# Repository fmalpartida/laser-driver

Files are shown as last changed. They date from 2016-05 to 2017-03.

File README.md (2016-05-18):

# Laser Driver
Small compact, constant current source for driving LEDs and lasers up to 4A with PWM capabilities and integrated support to drive 3 loads such as fans.

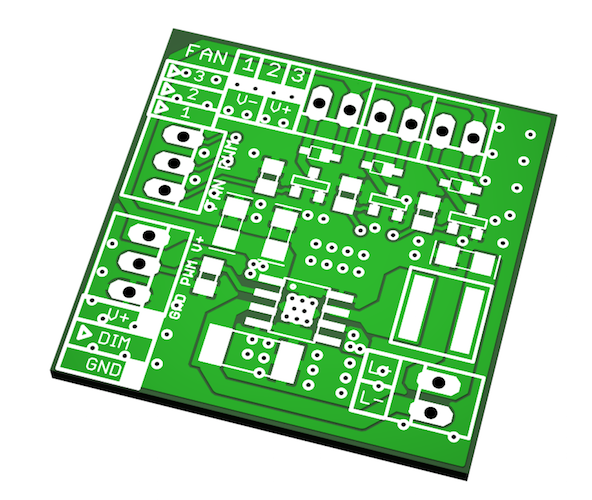
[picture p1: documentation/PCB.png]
Constant current driver PCB Constant current driver


## Board specification
### Schematic
[Last version of the schematic](./documentation/laserDriver_schematic.pdf)

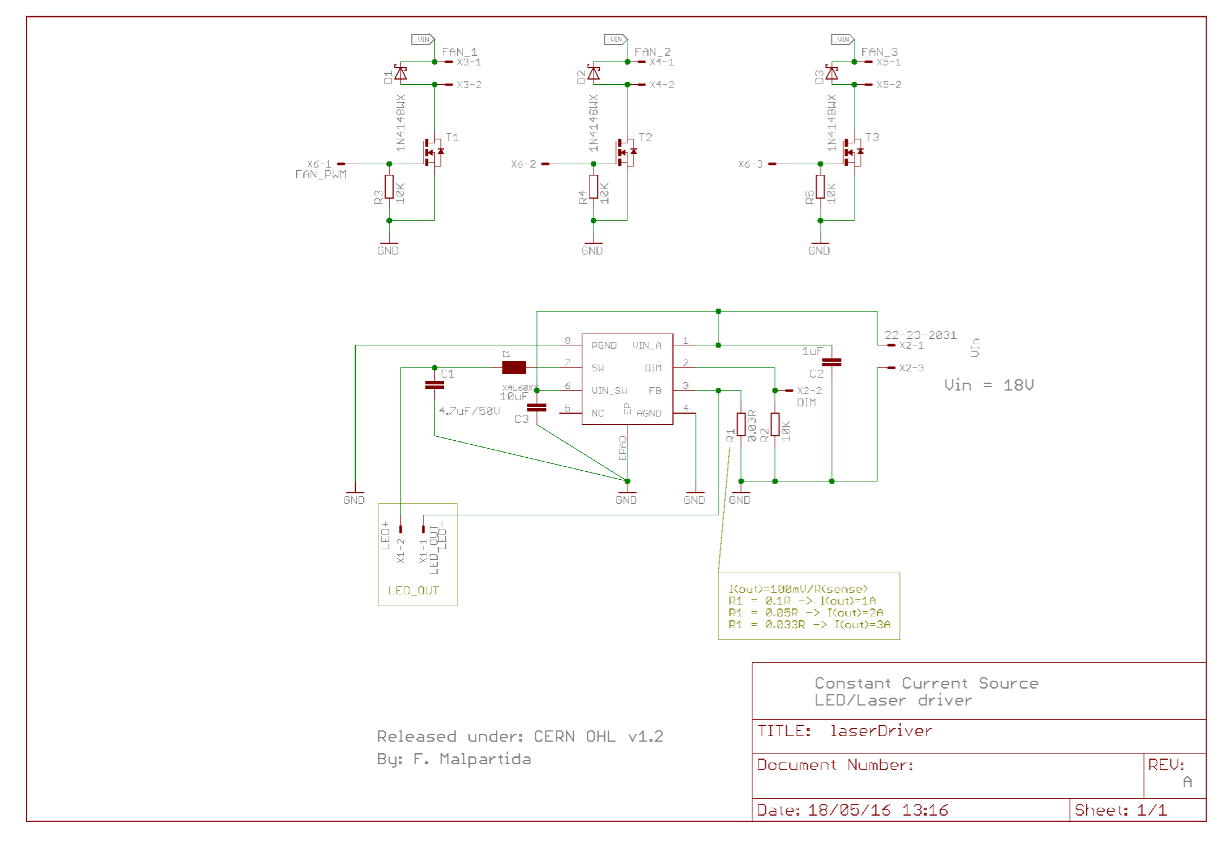
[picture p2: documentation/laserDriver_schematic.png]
Schematic Constant current driver schematic


### Electrical characteristics
   **V(in) range:**  4V..18V, *observe input caps ratings*

   **Max. main load current:** 3.3A *observe inductor ratings*

   **Max. aux load currents:** 500mA *depends on transistor selection*

   **Dim. threshold voltage:** 1.2V

   **Duty cycle range:** 0%..100%

   **Soft start duration:** 1.2ms

   **Dim. frequency range:** 400Hz..4KHz

### Mechanical
   **Board dimensions:** 32mm x 32mm

   **Supply and main load dimming:** 1 x 3 pin, 2.54mm connector

   **Main load connector:** 1 x 2 pin, 2.54mm connector

   **Aux. load dimm. connector:** 1 x 3 pin, 2.54mm connector

   **Aux. load connector:** 3 x 2 pin, 2.54mm connector

   **PCB fabrication:** Pattern class 6, drills clase C. Any cheap PCB manufacturer should be more than capable of making your boards. *Do not shrink track widths.*

*Observe connector current ratings for your application.*

### Measured performance
   **Performance:** Measure performance 83% @ 12V, 1A load. Tested with a 3W LED.

## Operation and setup

Constant current driver PCB Constant current driver

Connect power supply to the supply and main load dimming connector observing the polarity
(V+, DIM, V-) within the board's tolerance and ensure that your supply is capable of sourcing
the current required by your load.

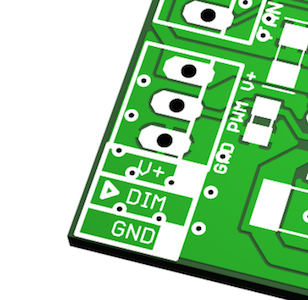
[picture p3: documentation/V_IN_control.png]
Supply Supply and main load dimming


Connect the load (LED or laser driver) observing the polarity of your device.

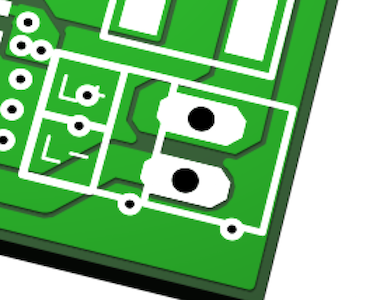
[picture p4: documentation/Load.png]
Load out


If you use auxiliary loads connect them to the auxiliary load connectors and observe their polarity.
The board has built in freewheel diodes, you should be good to go with any type of load provided you don't
exceed switching ratings.

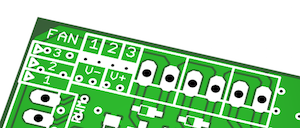
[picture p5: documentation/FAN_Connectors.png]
Fan connector Auxiliary load out


Each auxiliary load channel is controlled with a control signal from the aux load connector. By default
loads are inactive. A voltage level of 5V (depending on your FET selection) will activate each channel.

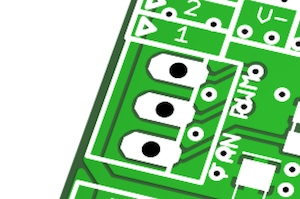
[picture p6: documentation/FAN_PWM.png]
Fan control Auxiliary load control


### Soft start
The board is configured to do a soft start. Apply a 1.2ms (minimum) pulse to the dimm pin before
starting the PWM operation.

## Waveforms and captures
A couple of waveform capture showing the performance of the driver. Measurement setup:
* Supply voltage: 5V
* Load current: 1A

To start the driver it needs a 1.1ms pulse on the dimming pin.
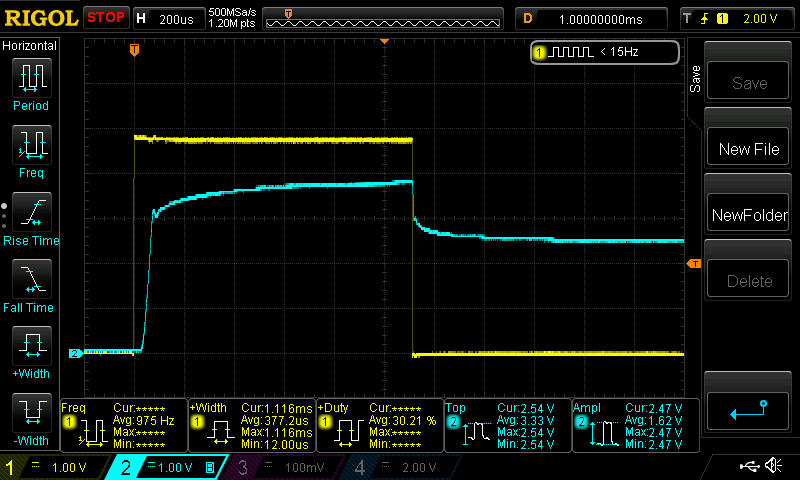
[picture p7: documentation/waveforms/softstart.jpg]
Soft Start Soft start pulse


976Hz PWM duty cycle captures.
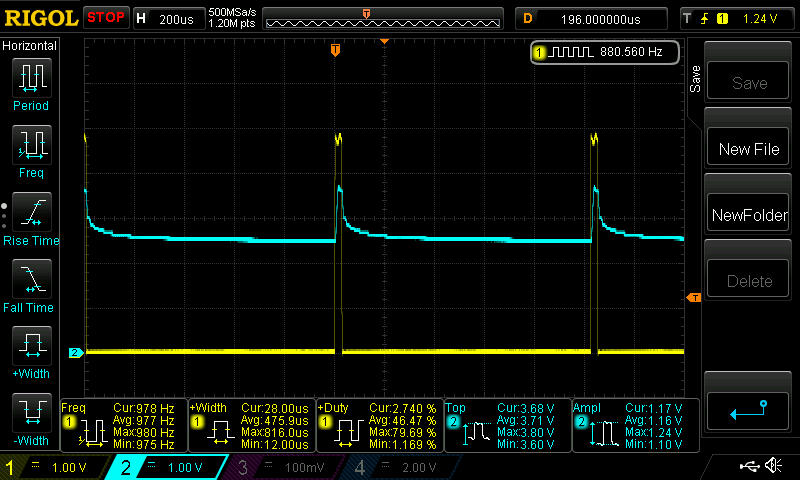
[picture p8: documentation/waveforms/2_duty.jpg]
2% duty cycle 2% duty cycle dimm

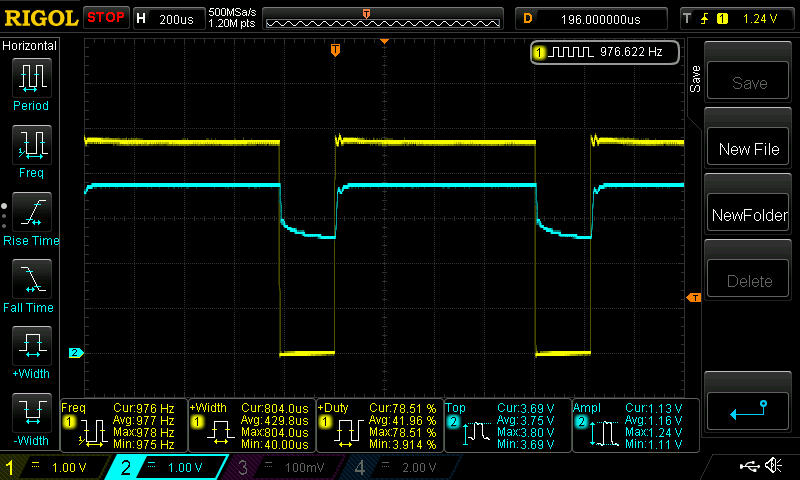
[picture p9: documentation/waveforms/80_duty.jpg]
80% duty cycle 80% duty cycle dimm


Raising edge, measuring directly the LED voltage on switch on. 10us, raising edge with very little
overshoot and ringing. Very decent current control and regulation.
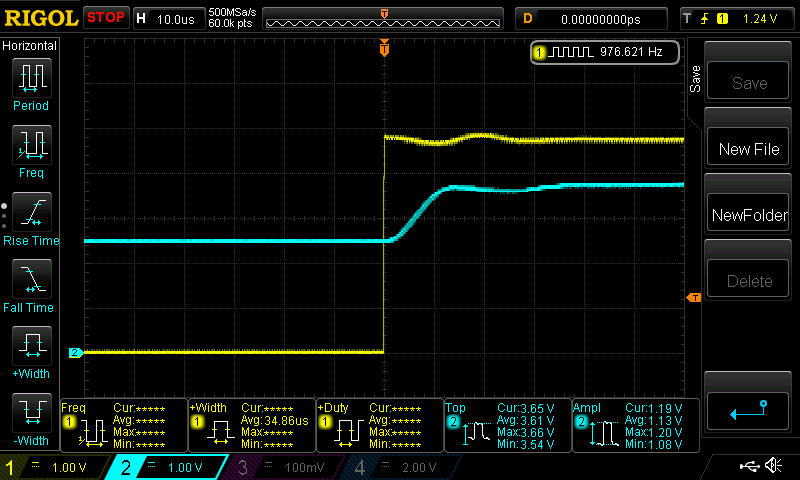
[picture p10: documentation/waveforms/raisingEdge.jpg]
Raising Edge Raising edge 10us


Ripple and noise is around 20mV, I think that about half of it comes from my measurement setup. 20MHz
bandwidth limit.
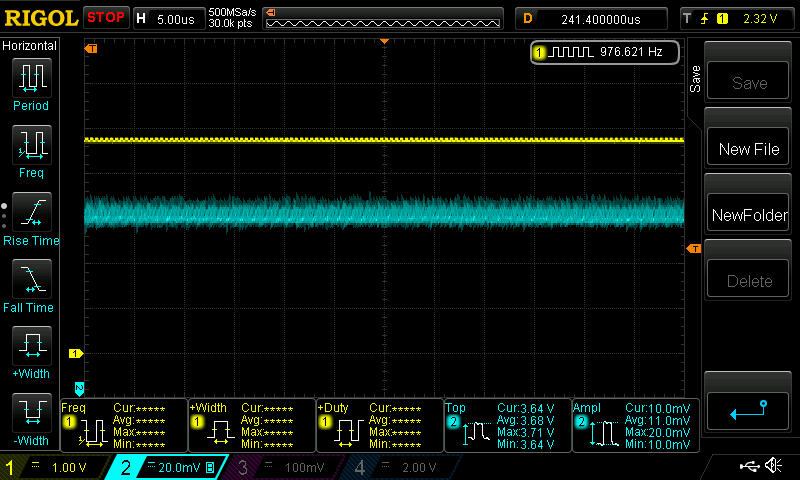
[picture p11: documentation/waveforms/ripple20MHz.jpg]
Ripple Ripple at 1A


## Disclaimer
The board has only been tested to switch a 3W LED driven at 1A. It should be more than capable of reaching
it's full specifications provided that you don't exceed the current ratings of the components you mount.

## License
The board is released under the CERN OHL v1.2 but if you like it and use it you can buy me some beer.
If you use it and/or do any derivative work from it, be nice and give attribution to the source.

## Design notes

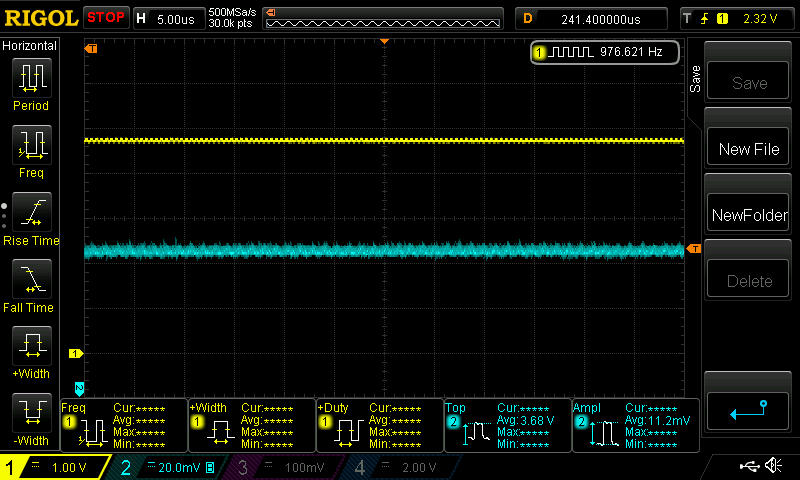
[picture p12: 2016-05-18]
documentation/waveforms/rippleFiltered.jpg

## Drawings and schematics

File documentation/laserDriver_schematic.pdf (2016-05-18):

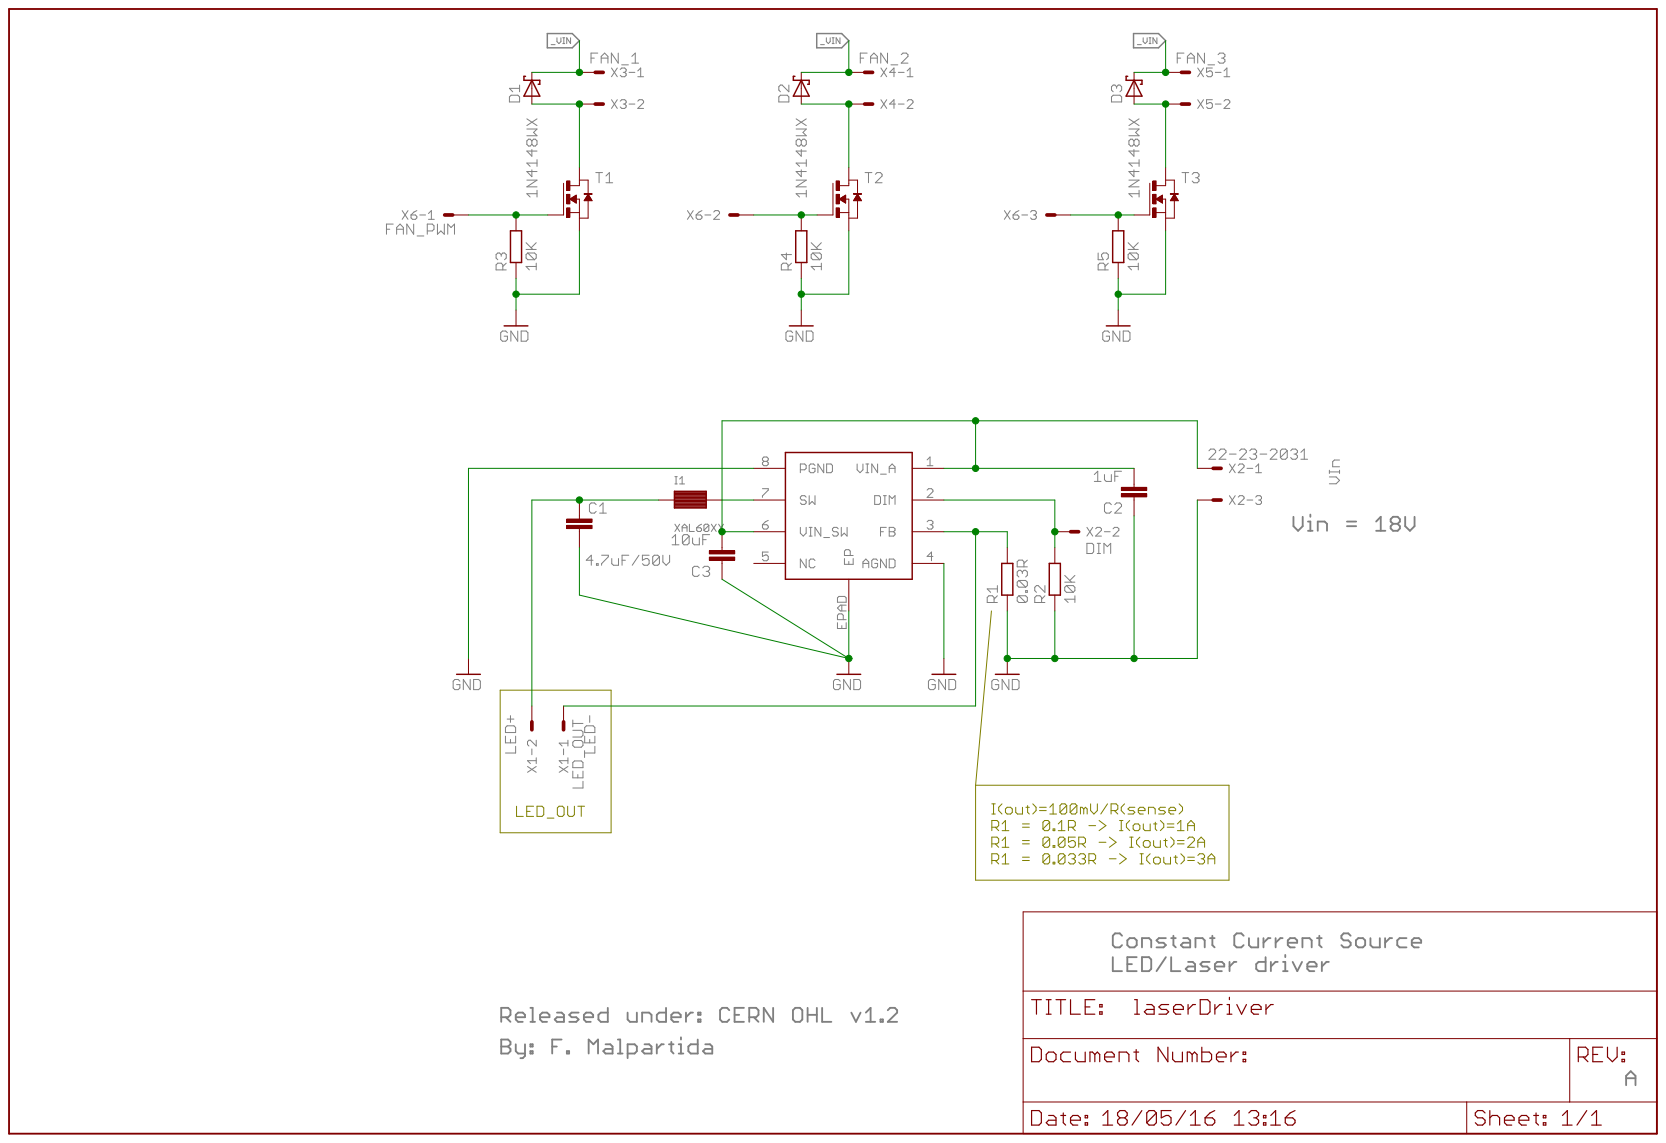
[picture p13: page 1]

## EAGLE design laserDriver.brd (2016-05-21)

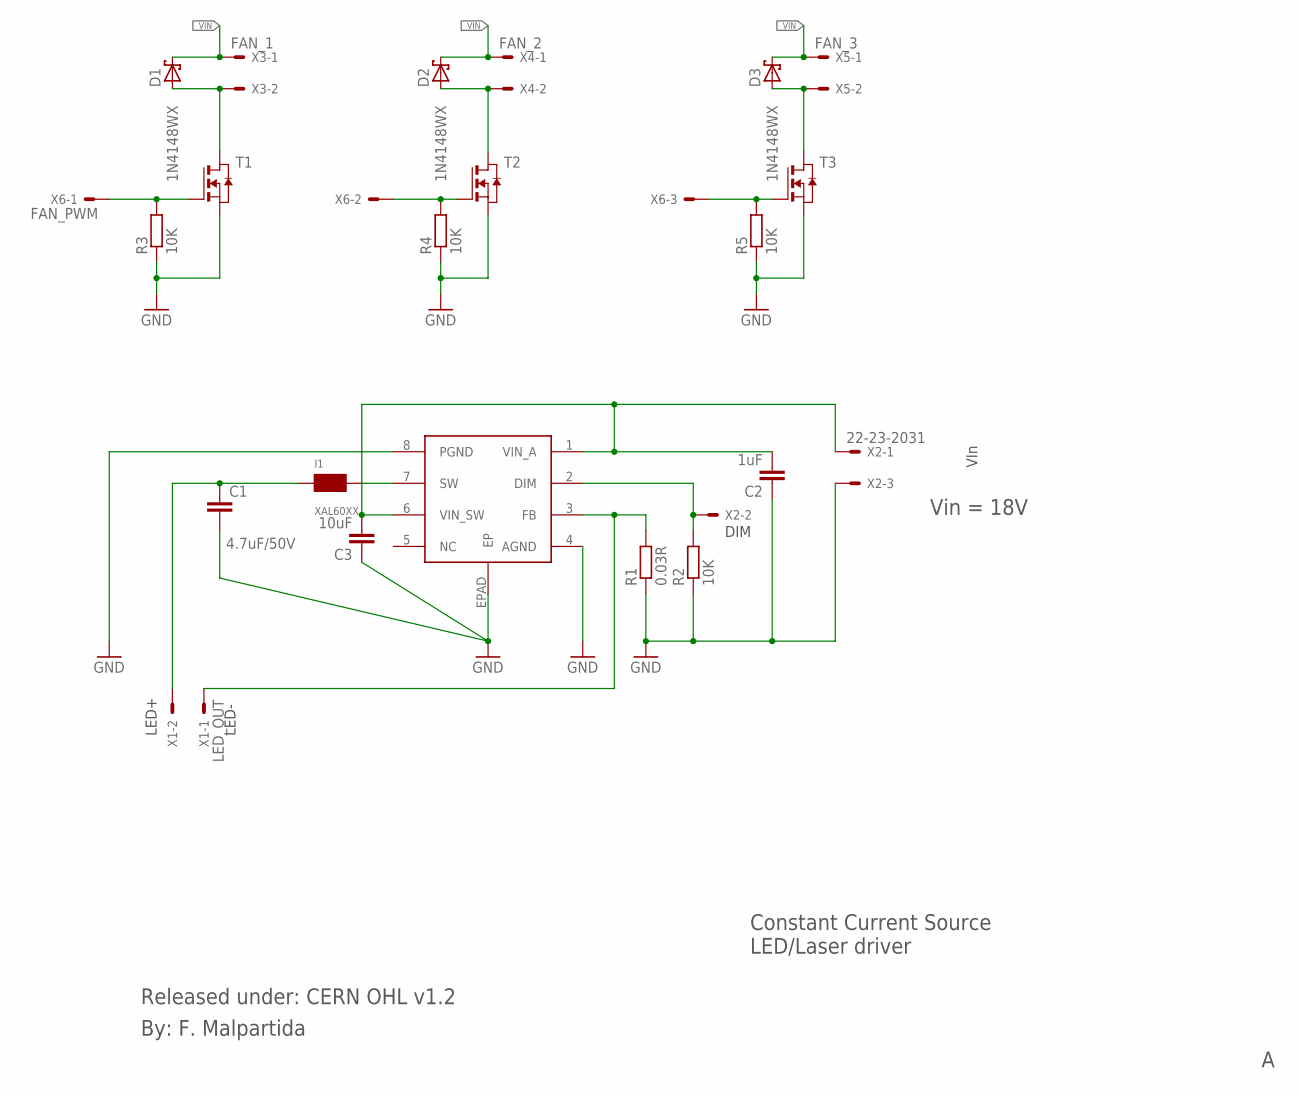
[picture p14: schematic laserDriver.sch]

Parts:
C1: 4.7uF/50V; C1206
C2: 1uF; C1206
C3: 10uF; C1206
D1, D2, D3: 1N4148WX; SOD323_ST
I1: XAL60XX
R1: 0.03R; R2512
R2, R3, R4, R5: 10K; M0805
T1, T2, T3: NMOSSOT23; SOT-23
U1: LED2001; SO08_PWR
X1: LED_OUT; 22-23-2021
X2: 22-23-2031
X3: FAN_1; 22-23-2021
X4: FAN_2; 22-23-2021
X5: FAN_3; 22-23-2021
X6: FAN_PWM; 22-23-2031

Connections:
GND: C1.2, C2.1, C3.1, R1.1, R2.1, R3.1, R4.1, R5.1, T1.2 (S), T2.2 (S), T3.2 (S), U1.4 (AGND), U1.8 (PGND), U1.EPAD (EP), X2.3
unnamed: R1.2, U1.3 (FB), X1.1
unnamed: I1.P$2, U1.7 (SW)
unnamed: D1.A, T1.1 (D), X3.2
unnamed: R2.2, U1.2 (DIM), X2.2
unnamed: D2.A, T2.1 (D), X4.2
unnamed: D3.A, T3.1 (D), X5.2
unnamed: R5.2, T3.3 (G), X6.3
unnamed: R4.2, T2.3 (G), X6.2
unnamed: R3.2, T1.3 (G), X6.1
_VIN: C2.2, C3.2, D1.C, D2.C, D3.C, U1.1 (VIN_A), U1.6 (VIN_SW), X2.1, X3.1, X4.1, X5.1
_VOUT: C1.1, I1.P$1, X1.2

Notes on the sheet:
LED+
LED-
VIn
DIM
Constant Current Source LED/Laser driver
Released under: CERN OHL v1.2
By: F. Malpartida
Vin = 18V

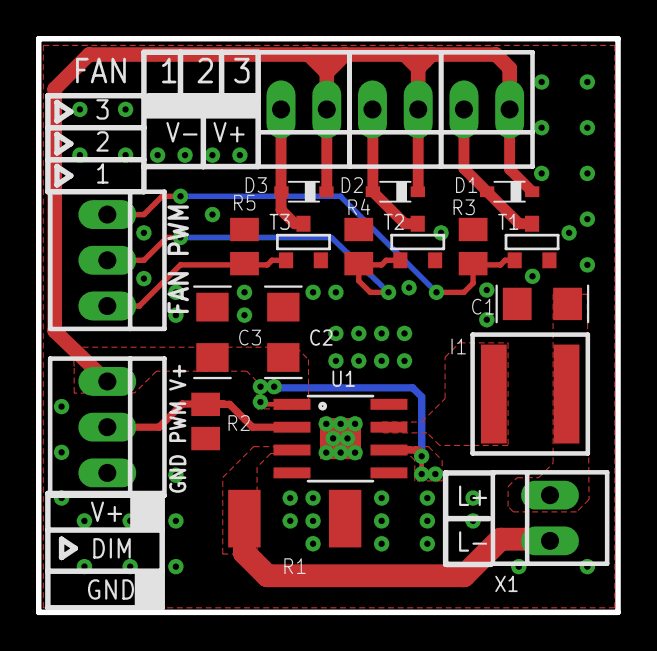
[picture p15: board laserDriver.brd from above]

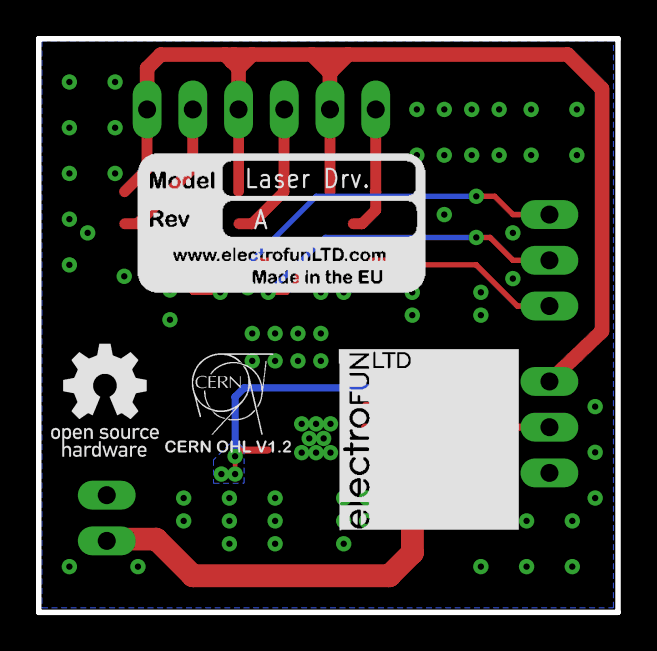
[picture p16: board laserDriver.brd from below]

Board: 2 copper layers, 32.2 x 31.9 mm, 26 parts (4 on the bottom side), 12 nets.

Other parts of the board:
U$1: OSHW
U$2: FMC_CERN_OHL
U$3: ELECTROFUN_10X10
U$4: BOARD_INFO_BMP_SMALL

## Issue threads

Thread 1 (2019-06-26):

LED Driver chip

Meshme, 2019-06-26:

troth530, 2021-02-27:
I have the same question.  Thank you.

fmalpartida, 2021-02-27:
And the question is?

troth530, 2021-02-27:
Sorry for being vague.  What is the 8 pin driver chip?  Thank you.

JRodrigoTech, 2021-02-27:
https://github.com/fmalpartida/laser-driver/blob/18474f128884661c4b68944d75d2ce46efa0ffbf/laserDriver.sch#L181

Closed 2019-06-27.

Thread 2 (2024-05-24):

Chip used ?

kjk25, 2024-05-24:
Hi, nice work and documentation, witch chip have you used ?

best wiches

fmalpartida, 2024-05-27:
Thank you so much. I can’t remember the chip I used. It should be in the Eagle files published. It is a constant current driver. I don’t have access to Eagle at this point, it’s been such a long time since I did this mini project…

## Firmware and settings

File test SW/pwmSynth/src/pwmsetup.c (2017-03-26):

#include <Arduino.h>

#define PWM_PIN  3

#define MAX_PERCENT 0.8
#define MAX_PWM (255 * MAX_PERCENT)
#define DELAY    100


void setup()
{
   pinMode ( PWM_PIN, OUTPUT );
   digitalWrite (PWM_PIN, HIGH);
   delayMicroseconds (1100);
   digitalWrite (PWM_PIN, LOW);
   delay (100);
}

void loop()
{
   for ( int i = 0; i < MAX_PWM; i++ )
   {
      analogWrite (PWM_PIN, i);
      delay(DELAY);
   }
   delay (2000);
   digitalWrite (PWM_PIN, LOW);
}

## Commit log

2016-05-18 Laser driver board and schematic. Revision A.
    [laserDriver.brd, laserDriver.sch]
2016-05-18 Added pdf schematic.
2016-05-18 Minor PCB touch ups. Updated README file.
    [laserDriver.brd]
2016-05-18 Added schematic image.
2016-05-21 Minor changes.
    [laserDriver.brd]
